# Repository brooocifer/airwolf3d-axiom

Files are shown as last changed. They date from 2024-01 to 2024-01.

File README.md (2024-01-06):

# airwolf3d-axiom
Files for the Airwolf3D Axiom printer

A friend gave me an old, used Airwolf3D Axiom printer in late 2023. Airwolf3D no longer manufactures or supports this printer. Some of the printer parts themselves are 3d printed, including the Bowden extruder, and there are no STL files available online for them (Airwolf3D, please make these available!). Newer slicing software does not support this printer, so some configuration is needed to use. This is a collection of files and information I had to gather from multiple sources or reverse engineer to get this printer working for me.

Last website version for this model: https://web.archive.org/web/20210512170901/https://airwolf3d.com/shop/aw3daxiom

Brochure: https://web.archive.org/web/20161227010145/http://airwolf3d.com/wp-content/uploads/2015/07/AXIOM-3D-Printer-Brochure.pdf

Support Files: https://airwolf3d.freshdesk.com/support/solutions/13000002887

Directories
- cura - Cura Ultimaker Pro slicing software does not natively support this printer
- extruder - The Bowden extruder that came with the printer had degraded (cracked) and was unusable
- glass - There was no glass plate in the printer when I received it
- wifi - What I've learned about using the Wifi hotspot

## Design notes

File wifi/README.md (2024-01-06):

# Wi-Fi

I didn't realize this printer had Wi-Fi until I was looking through the support files. There are two main articles of interest:

- AXIOM Single Bowden - Wolfbox - Connecting to the Printer: https://airwolf3d.freshdesk.com/support/solutions/articles/5000663358-axiom-single-bowden-wolfbox-connecting-to-the-printer
- AXIOM/AXIOMe Enable the hotspot: https://airwolf3d.freshdesk.com/support/solutions/articles/13000000433-axiom-axiome-enable-the-hotspot-

I read through the first article, and with some quick scanning, was happy to see that the hotspot was available. Here are the full steps I took to get Wi-Fi working, and cloud printing working via Astroprint.com.

1. Create an account at astroprint.com (Note: use https://www.astroprint.com. If you don't use www, there is a certificate error)
2. Follow the steps in the first article above. I used my iPhone to do this.
- Note that step 7 of the article failed for me (The issue was that the raspberry pi thought it was July 5, 2016. I corrected the issue later, see below), so I just skipped the step using the "skip" link on the page.
- Note also that step 8 of the article requires a USB cable to be connected (near the extruder on the back of the printer). You have to leave the USB cable connected in this manner for cloud printing to work via astroprint.com.
3. The second article implies that the Wi-Fi is enabled via a Linaro Linux "Wolfbox". In reality, there is a raspberry pi built into the back panel. You don't need to hook up a keyboard and monitor like the article implies. Once you have connected to your home network, you can just use ssh (port 22) or http (port 80) to connect to the raspberry pi.
4. Just a suggestion, I set a dedicated IP address for my printer on my network, and rebooted the printer to enable it. Browse to the IP address (dedicated or dynamic) in a browser to test that your printer is connected to the network.
5. Fix the pi time via NTP:
- ssh pi@192.168.10.40 (or whatever your printer IP address is - password is "raspberry")
- sudo service astrobox stop
- sudo timedatectl set-ntp True
- timedatactl status (to validate that NTP set the correct current time)
- sudo service astrobox start
- exit
6. Browse to the local (astrobox) web page: http://192.168.10.40
7. Use the hamburger menu in the upper left, and login to astroprint.com
8. Go to "Settings"
9. Validate that you are connected to the printer at 250,000 baud.
10. Software Update - mine is at v0.9(2) - updates fail. Essentially this version of the Raspberry Pi OS is no longer supported. Don't bother trying to update
11. Camera - I happen to own a Logitech C615, so this worked well for me: https://www.thingiverse.com/thing:1424061
- Note: the thing page shows the camera mounted in the upper right front of the printer. I found that this gets in the way of opening and closing the front door. I mounted it instead on the upper left front of the printer, and installed the arm upside down, so that the camera is looking down through the top acrylic rather than the front. You have to take the back off of the printer to find the raspberry pi and plug the camera USB into it. Once it was plugged in, I used the camera settings page to rescan for the camera and configure it.
Once logged into https://cloud.astroprint.com, you can monitor and manage your printer via the "Monitor" button.

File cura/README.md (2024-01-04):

# Cura Ultimaker Pro

I don't have Airwolf3D's APEX software, and I have absolutely no interest in it. I've been using Cura Ultimaker Pro for years so why change now?

Except that Cura supports practically every 3D printer manufacturer except Airwolf3D. Or maybe Airwolf3D doesn't want Cura to support them, since they have competing software.

Either way, it takes manually setting up Cura to use it.

I'm not finding a HOWTO article for this EOL'd printer, but there are articles on Airwolf3D's currently supported printers, so I've created a HOWTO based on those. I also had the sample print files, so some reverse engineering was necessary to fill in some blanks.

When I first tried to print based on the configuration settings and profiles using Airwolf3D's sample STL's, I was having issues, as it looked like the printer was trying to print 0.5mm too high above the glass plate. It turns out that it really was, but it wasn't due to the configuration.

Airwolf3D provided STL files where the model is not layed flat on the Z axis zero plane, but are in fact floating at 0.4mm! This seems like such a rookie mistake on Airwolf3D's part, I didn't even consider that their STL models were screwed up! Booooooooooo! Looking through the library of provided STL files, I found that they all have issues, some are even consistently rotated sideways rather than flat.

Once I used Cura to lay the model flat, rotated it where I wanted it, and then re-sliced, the resulting GCODE file printed the model with no problems.

So with my whining and complaining out of the way, here are the HOWTO steps needed to enable the use of Cura Ultimaker Pro for this printer:

1. Download and install Cura, if you haven't already
2. Open Settings or Preferences, and go to Manage Printers
3. Add a non-networked, Custom FFF Printer
4. Name it something meaningful, I used "Airwolf3d Axiom"
5. In the Machine Settings, Printer Settings, set the following:
-  X (Width) : 340.0 mm
-  Y (Depth) : 203.0 mm
-  Z (Height) : 254.0 mm
-  Build Plate Shape: Rectangular
-  Origin at cetner : Unchecked
-  Heated Bed : Checked
-  Heated build volume : Unchecked
-  G-code flavor: Marlin
6. In the Machine Settings, Printhead Settings, set the following:
-  X min : -20 mm
-  Y min : -10 mm
-  X max : 10 mm
-  Y max : 10 mm
-  Gantry Height : 254.0 mm
-  Number of Extruders : 1
-  Apply Extruder offsets to GCode : Checked
7. In the Machine Settings, Start G-code, set the following : use the contents of the start.gcode file from this folder
8. In the Machine Settings, End G-code, set the following : use the contents of the end.gcode file from this folder
9. In the Machine Settings, Extruder 1, set the following :
- Nozzle size : 0.5 mm
- Compatible material diameter : 3.0 mm
- Nozzle offset X : 0.0 mm
- Nozzle offset Y : 0.0 mm
- Cooling Fan Number : 0
10. In the Machine Settings, Extruder 1, Extruder Start G-code, leave it blank/empty
11. In the Machine Settings, Extruder 1, Extruder End G-code, leave it blank/empty
12. In the Profiles section of Settings/Preferences, create custom profiles by importing the profile files for different filament types and qualities. These files came with my printer, and were provided by Airwolf3D

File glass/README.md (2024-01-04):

# Glass

There was no glass plate in the printer when I received it, a detail I didn't notice until I tried my first test print and the print head started dropping ABS from a few millimeters too high!

Luckily the Axiom printer shares the same glass plate dimensions as some of Airwolf3D's other still supported printers. 

Replacement parts are available at: https://airwolf3d.com/product-category/3d-printer-replacement-parts/.

I ordered the "AXIOM and EVOR Double Sided FLEX-RESISTANT GLASS" for $45.00, along with a bottle of Wolfbite Original from https://airwolf3d.com/product-category/3d-printer-adhesive/.

I ordered about 2 weeks before Christmas, it took Airwolf3D 15 calendar days to fulfill my order, and they shipped it via UPS Ground the day after Christmas. I'm only 2 states away (a 6 hour drive) away from their location, so it was delivered 2 days later.

The Wolfbite application was quick and simple (see the video at the next link), installation was easy (https://airwolf3d.freshdesk.com/support/solutions/articles/13000048097-axiom-single-bowden-installing-glass-plate).

I'm really pleased with how well the printed models stick to the plate during printing, and how easily they detach from the cool plate.

Success! For only $77.82 (includes shipping and taxes)

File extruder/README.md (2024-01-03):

# Extruder

The Bowden extruder that came with the printer had degraded (cracked) and was unusable. No STL file was available anywhere online that I could find.

Apparently, Airwolf3D recommends converting the printer from a Bowden extruder model to a direct drive model, but for a free printer, I really wasn't interested in spending a lot of money to do this.

Also, I've wanted to learn how to use Blender to create my own 3D models, and this was a great opportunity to do so. I spent a lot of time learning Blender, and ended with a result that is workable, but not without a few issues. Basically, I was exhausted with it when I had a version that was workable, and didn't fix all the problems that probably should have been fixed.

The resulting file is available here as extruder_assembly_final.blend and extruder_assembly_final.stl.

Notes, things I learned:
- A digital caliper is a requirement. Measurements with a manual caliper were way off.
- Buy replacement batteries for your digital caliper beforehand. Lots of measuring.
- The digital caliper from Harbor Freight was good enough, although margin of error was probably still too high for this reverse engineering effort. I did 6 major revisions to the model to fix measuring errors.
- In Blender, if you cut too much volume out of an object, you can just create a new 3D object and "glom" it on to the original. I'm sure some engineer somewhere thinks this is a hack and not the proper way to design this, and it makes for a *really* messy model, but frankly, I don't care. It works.
- A good soundtrack is essential.
- I printed my first one in PLA on my old 3D printer. I had to modify the part with a drill, and by applying some manual force. The PLA gave enough for this to work, YMMV on other materials.
- Instructions for assembly/disassembly are here: https://airwolf3d.freshdesk.com/support/solutions/articles/5000684875-axiom-extruder-assembly-dissassembly
- The screw holes for the spring plate are too small. I just used a drill with a phillips driver to screw the screws in all the way, then backed them all the way out before starting assembly.
- Similarly, the 3 bolt holes that bolt into the acrylic plates are slightly too small. I used the drill and phillips driver on those too.
- The bolts that go through the back panel and attach to the acrylic plates are a huge pain because you have to reach through the open front door with one hand while holding the acrylic plates with the other. Get a 2nd person to help if you can. I have long arms and I could barely reassemble it by myself.
- The hole for the main shaft and bearing is very tight. Snap it in and remove it a couple times before trying to do final assembly, this will "stretch" or erode the PLA enough that it will end up being a snug fit. I found it impossible to assemble all the parts onto the acrylic plates before I started over and did this first.
- The hole for the spring that is held in place by the spring plate is still too small. I used a drill and a drill bit to round it out enough that the spring could be inserted and "spring" appropriately.
- On one of my assembly attempts, the extruder was not fully flush against the acrylic plates. It turns out that the black adapter on the end of the filament tube was not snapped in correctly, and was slightly twisted. Make sure it is snapped in flush with the extruder surface edge.
- After assembly, I found that loading both ABS and Nylon filament was impossible with the spring plate screwed all the way in. I backed it off almost all the way out to reduce the pressure between the main shaft and the sliding bearing, and now both filament types load easily.

Overall, it was fun, as most reverse-engineering/hacks are. Good luck!

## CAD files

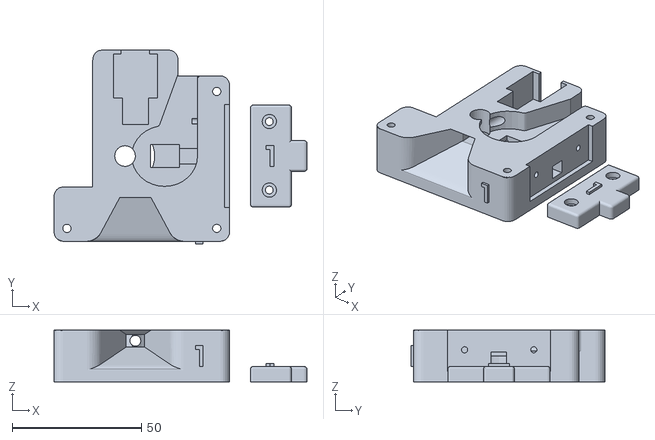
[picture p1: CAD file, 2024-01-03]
extruder/extruder_assembly_final.stl
97.9 x 75.0 x 20.0

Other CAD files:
extruder/extruder_assembly_final.blend
